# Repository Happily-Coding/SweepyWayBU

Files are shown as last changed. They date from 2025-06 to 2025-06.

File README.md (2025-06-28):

# SweepyWay Split Keyboard
A truly ergonomic, begginner friendly keyboard.

## Photos & Outputs

left side | right side
-|-
left | right

[More outputs](https://happily-coding.github.io/SweepyWay/) 
<!-- 
![left bottom](https://happily-coding.github.io/SweepyWay/images/left_pcb-bottom.png) | ![right bottom](https://happily-coding.github.io/SweepyWay/images/right_pcb-bottom.png)
-->

## Features
* **Beginner friendly**
  * Abundant keys, but in non disruptive places.
* **Truly ergonomic**
  * Aggressive column stagger, like Ferris Sweep, to match how fingers are staggered.
  * Choc V1 keys
    * Very low actuation force switches available (example: nocturnal)
    * Low profile (seamless use without handrest, easier to adjust height without an adjustable desk)
    * ChocV1 spacing (reach the outer columns with less over-stretching)
  * Tenting, negative tilting, adjustable height and hand rest solutions
* **Energy efficient**
  * [Nice!nano](https://nicekeyboards.com/nice-nano) optimised, but any promicro should work (bottom up) 
  * [Nice!view](https://nicekeyboards.com/nice-view) support
  * No leds
* **Accident prepared** 
  * Controller far away from accidental splash zones,
  * Power switch for transport
  * No metal plates to help prevent static discharge from friying the keyboard
  * Hotswappable battery, switches, keycaps, controller, and case. Replace anything that breaks or you dislike.
    * You can even remove the components and use them with a different pcb.
* **Easy to modify** (Declarative design done via yaml)
  * Layout is declared using [Ergogen](https://github.com/mrzealot/ergogen/). 
  * Uses Ergogen to translate YAML to a KiCad PCB and plate files for FR-4 fab or laser cutting
  * Uses [kicad-automation-scripts](https://github.com/productize/kicad-automation-scripts) and [FreeRouting](https://github.com/freerouting/freerouting) to **automatically route the traces on the PCB**
  * Uses [KiKit](https://github.com/yaqwsx/KiKit) to render PCB previews and production-ready **Gerber files**

## Build Status


<!-- from original repo
## Todo
Mio:
Paso 1: mover todos los electronicos para arriba con mismo ofset
mcu_nice_nano
display_nice_view
battery_connector_jst_ph_2
reset_switch_tht_top
utility_ergogen_logo
version_txt
power_switch_smd_side
polygon arriba

Paso 2: sacar cosas raras/ tratar de simplificar el file

Paso 3:
hay que recrear el area, y reorganizar componentes como mi original
hay que recrear el outline y organizar componentes como el original (pero todavia no)

* Bottom Plate (Thick PCB with cutouts for all components placed at the bottom. Optimised for maximum thinness)
* Remove or document magic numbers
* SMD footrints
* Middle bracked PCB with touchpad (Holds both halves together rigidly)
* stabilizer cutouts Needs more research...
  Thanks https://github.com/jasonhazel for measuring the ChocFox WOB 3u spacebar stabilizer spacing. (40mm)
  watch https://www.youtube.com/watch?v=5tERUZ_BSPM
-->

## How to modify it
<!-- from original repo
### Add more keys in places that don't interfere with the controller
Add elements to the row or column matrix, and map them (WIP, TODO explain with more detail)

### Use other controllers

### Use mx switches / chocv2 switches

### Use other battery/reset switches/ footprints
See this examples: 
https://github.com/jsbursik/Janus-Keyboard mx nice nano reversible with custom footprints
https://github.com/tarneaux/triboard xiao controller choc spaced reversible with battery polygon!
https://github.com/Henkru/novum mx with jlpcb target, middle layer for stability, and awesome background art
https://github.com/Musab-Hassan/aurora_keyboard very detailed, and well organized mx example
https://github.com/soundmonster/samoklava/tree/main
https://github.com/christianselig/caldera-keyboard/blob/main/ergogen/config.yaml
https://github.com/jusdisgi/splaveferris/blob/main/ergogen/config.yaml (choc v1, smd) <-- reference for mirrored
https://github.com/jusdisgi/biggie-splays/blob/main/biggie-splays_choc_v1/config.yaml mirror matrix
https://pastebin.com/JzsmATYZ celoide reversible (obtianed from atreus/absolem discord) https://cdn.discordapp.com/attachments/759825860617437204/1376609916986327150/pleiades.yaml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
Complex case, and mounting example with celodie footpritns https://github.com/MalusKnight/SplitMax-Ergogen/blob/main/config.yaml and oleds
https://github.com/Nuclear-Squid/Quacken/blob/main/config.yaml [ro micro non celoide]
https://peterlyons.com/problog/2024/05/kipra-keyboard/ how to load an ergogen otuput to freecad 
https://github.com/johnlamb/LambBT/blob/main/ergogen/config.yaml case, m2 screwes, etc 
https://github.com/AtomicJon/jonkey/blob/main/jonkey-v2.yml other celoide footprints usage
https://github.com/scipioni/clavis alternative stup for auto routing 
#asym in theory can be used in outlines to get only mirrored or only normal points https://docs.ergogen.xyz/outlines/
-->

If you would like to modify this:
* fork it
* change `ergogen/config.yaml` to your liking
* reactivate github workflows
* reactivate github pages at https://github.com/your-name/your-repo/settings/pages, choose github actions instead of a branch
* push your changes; the `build.yml` GitHub Workflow will pick it up, autoroute and generate Gerbers, all in a zip file.
  See https://github.com/soundmonster/samoklava/actions
* or:
  * make sure to have Docker CLI and NodeJS installed
  * run `make setup clean all`
  * check the `output` folder for KiCad PCBs and Gerbers
* you can find the latest build artifacts [here](https://happily-coding.github.io/SweepyWay/)

See the [workflow](.github/workflows/build.yml) or the [Makefile](Makefile) for more details.

## Credits
- [mxooaar](https://www.reddit.com/r/ErgoMechKeyboards/comments/1lanvon/comment/mxooaar/) for peaking my interest in actually building my idea for a keyboard
- [christianselig caldera keyboard](https://github.com/christianselig/caldera-keyboard) for showing that creating a custom keyboard was reasonably easy
- [Ergogen](https://github.com/ergogen/ergogen) for the awesome tool for building most of the keyboard
- [Soundmonster Samaklova Keyboard](https://github.com/soundmonster/samoklava/tree/main) for automatic electronic routing
- [tbaumann typematrix](https://github.com/tbaumann/typematrix_split_new/tree/main/ergogen) for automatic documentation, and example of how to use celoide ergonomic footprints
- [Celoide](https://github.com/ceoloide/ergogen-footprints) for the library of additional ergogen footprints for more parts.

## Disclaimer
**Work in progress!**

## Important
Only connect battery if a nice!nano board is used!

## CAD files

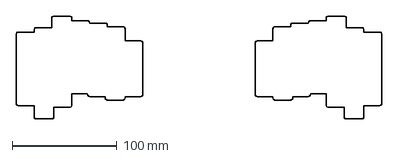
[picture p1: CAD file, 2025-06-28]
ergogen/output/outlines/key_based_board_outline_left.dxf
349.0 x 98.2 mm

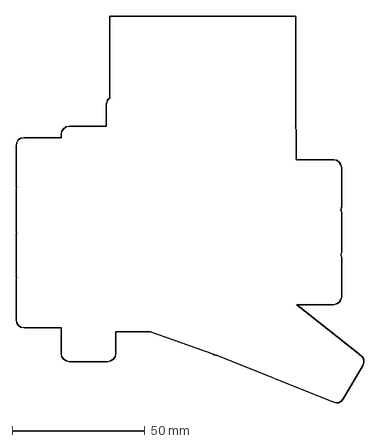
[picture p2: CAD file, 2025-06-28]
ergogen/output/outlines/l_pcb_outline.dxf
131.3 x 146.0 mm

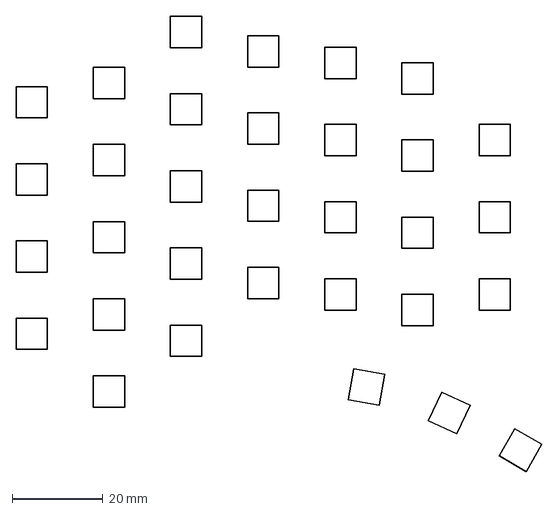
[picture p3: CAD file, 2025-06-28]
ergogen/output/outlines/l_keys_outline.dxf
115.9 x 100.3 mm

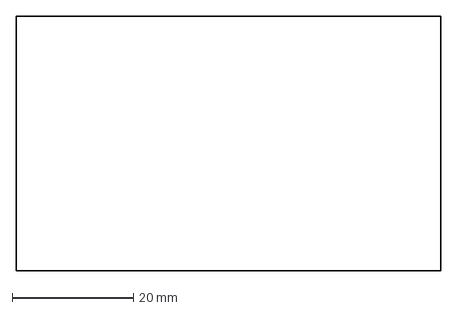
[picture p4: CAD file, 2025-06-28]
ergogen/output/outlines/l_controller_area.dxf
70.0 x 42.0 mm

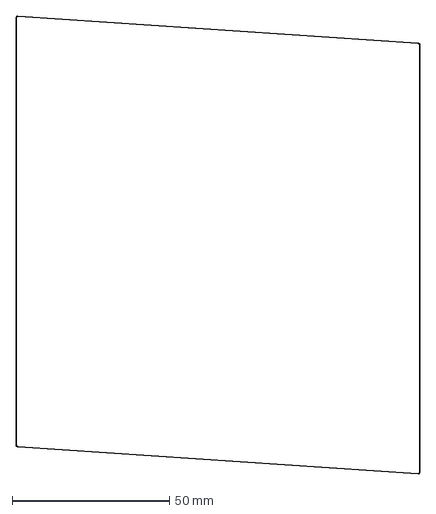
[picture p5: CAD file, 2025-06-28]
ergogen/output/outlines/bottomright.dxf
128.5 x 145.6 mm

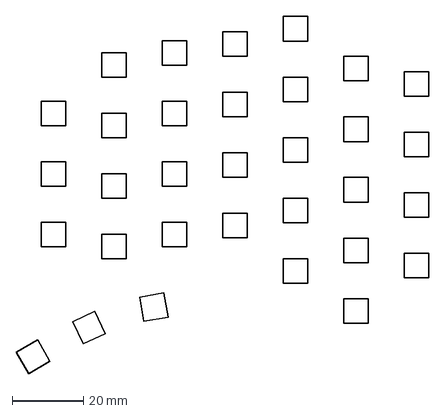
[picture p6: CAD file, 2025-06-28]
ergogen/output/outlines/r_keys_outline.dxf
115.9 x 100.3 mm

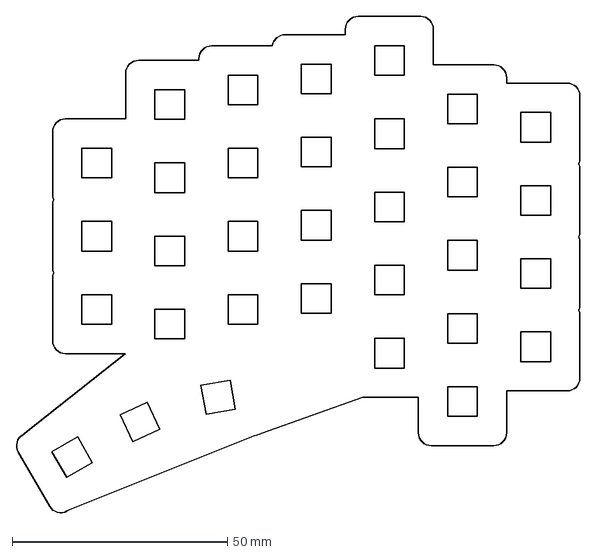
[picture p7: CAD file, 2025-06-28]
ergogen/output/outlines/r_cover_outline.dxf
131.0 x 115.7 mm

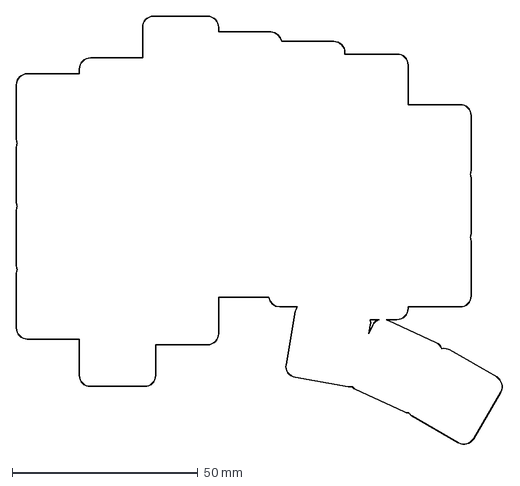
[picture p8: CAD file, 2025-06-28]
ergogen/output/outlines/l_key_based_board_outline.dxf
131.3 x 115.7 mm

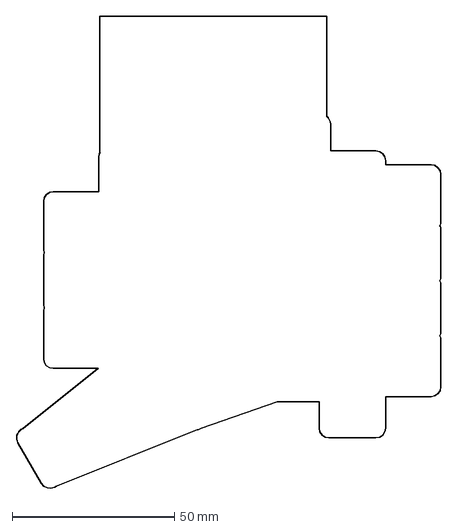
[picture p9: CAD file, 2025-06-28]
ergogen/output/outlines/r_pcb_outline.dxf
131.0 x 146.0 mm

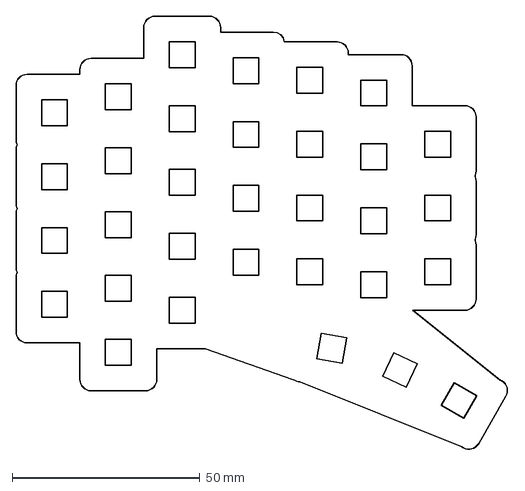
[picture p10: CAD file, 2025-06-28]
ergogen/output/outlines/l_cover_outline.dxf
131.3 x 115.7 mm

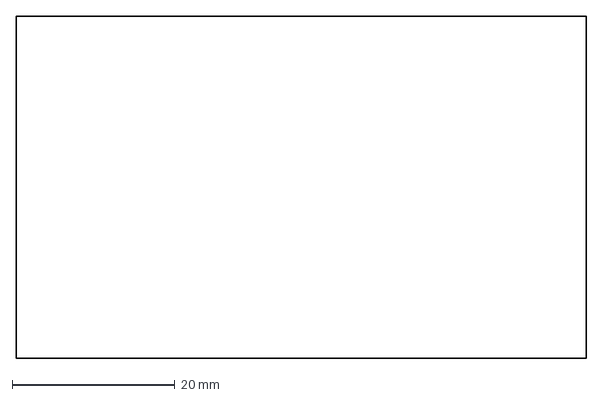
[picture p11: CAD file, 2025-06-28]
ergogen/output/outlines/r_controller_area.dxf
70.0 x 42.0 mm

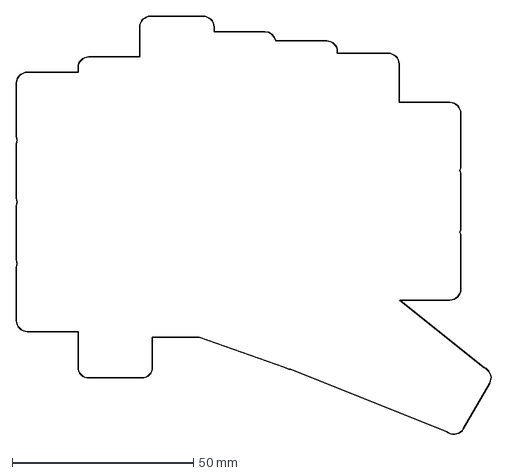
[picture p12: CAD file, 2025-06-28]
ergogen/output/outlines/l_all_key_clusters_outline.dxf
131.3 x 115.7 mm

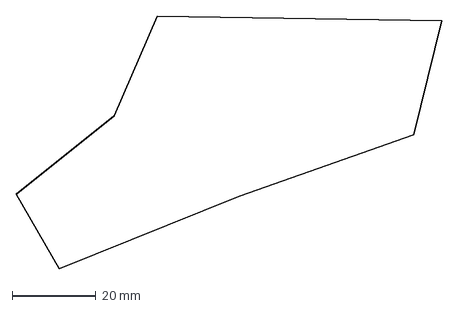
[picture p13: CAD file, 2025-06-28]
ergogen/output/outlines/r_thumb_suplementary_outline.dxf
101.7 x 60.2 mm

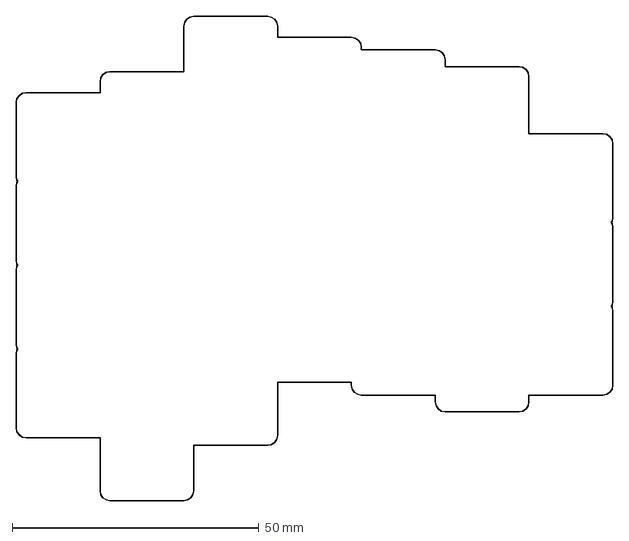
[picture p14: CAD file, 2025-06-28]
ergogen/output/outlines/key_based_board_outline.dxf
121.0 x 98.2 mm

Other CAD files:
ergogen/output/outlines/all_key_clusters_outline.dxf
ergogen/output/outlines/topleft.dxf
ergogen/output/outlines/thumb_suplementary_outline.dxf
ergogen/output/outlines/bottomleft.dxf
ergogen/output/outlines/combined.dxf
ergogen/output/outlines/cover_outline.dxf
ergogen/output/outlines/l_thumb_suplementary_outline.dxf
ergogen/output/outlines/left_pcb_outline.dxf
ergogen/output/outlines/pcb_left.dxf
ergogen/output/outlines/r_all_key_clusters_outline.dxf
ergogen/output/outlines/r_key_based_board_outline.dxf
ergogen/output/outlines/topright.dxf

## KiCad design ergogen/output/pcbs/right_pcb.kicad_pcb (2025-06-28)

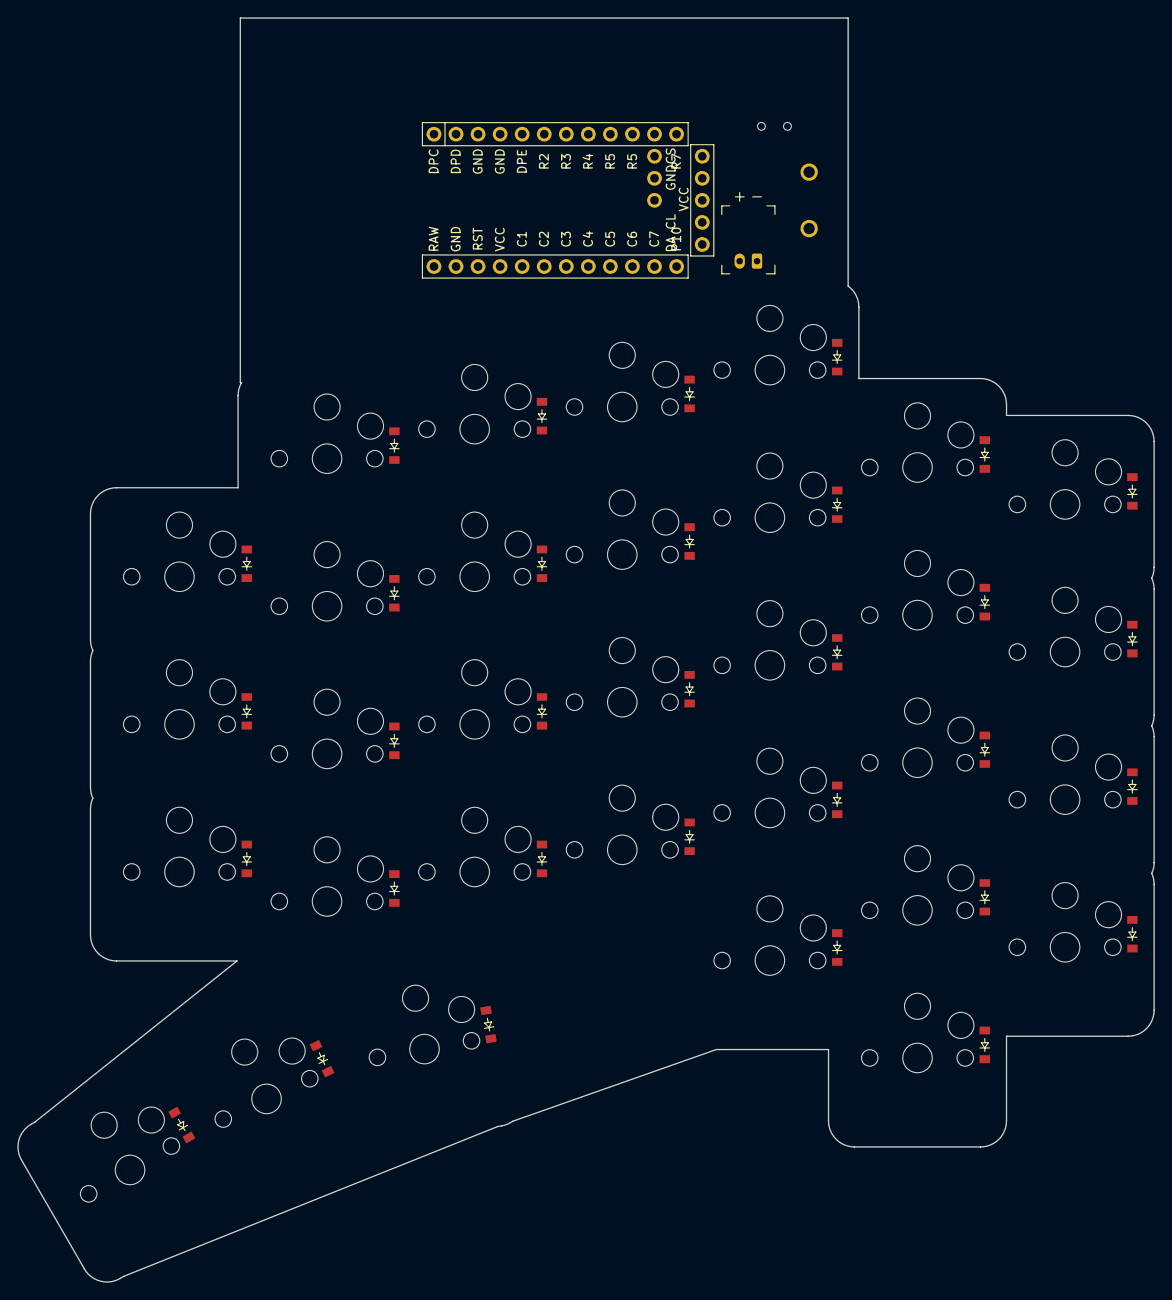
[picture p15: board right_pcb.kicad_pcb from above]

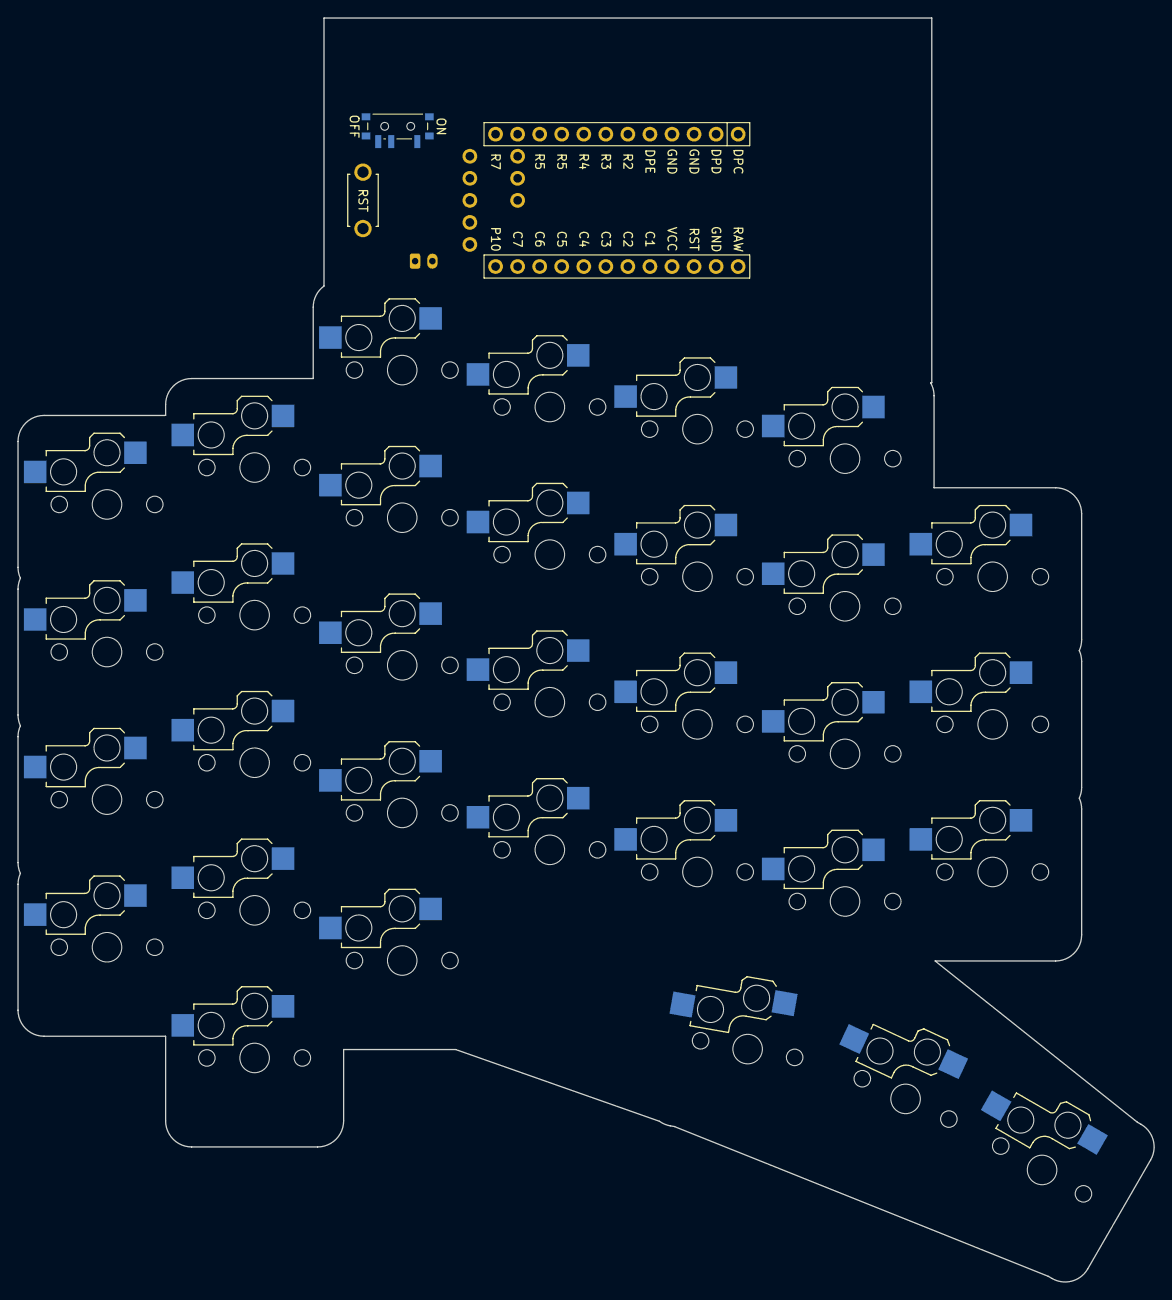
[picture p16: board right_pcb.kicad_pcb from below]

Board: 2 copper layers, 130.8 x 145.6 mm, 69 parts (34 on the bottom side), 52 nets, no tracks yet.

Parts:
D1, D2, D3, D4, D5, D6, D7, D8, D9, D10, D11, D12, D13, D14, D15, D16, D17, D18, D19, D20, D21, D22, D23, D24, D25, D26, D27, D28, D29, D30, D31, D32: diode_tht_sod123
DISP1: display_nice_view
JST1: battery_connector_jst_ph_2
MCU1: mcu_nice_nano
PWR1: power_switch_smd_side
RST1: reset_switch_tht_top
S1, S2, S3, S4, S5, S6, S7, S8, S9, S10, S11, S12, S13, S14, S15, S16, S17, S18, S19, S20, S21, S22, S23, S24, S25, S26, S27, S28, S29, S30, S31, S32: switch_choc_v1_v2

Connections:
BAT_P: JST1.2, PWR1.1
C1: MCU1.20, S1.2, S2.2, S3.2, S4.2
C2: MCU1.19, S5.2, S6.2, S7.2, S8.2, S9.2
C3: MCU1.18, S10.2, S11.2, S12.2, S13.2, S14.2
C4: MCU1.17, S15.2, S16.2, S17.2, S18.2
C5: MCU1.16, S19.2, S20.2, S21.2, S22.2
C6: MCU1.15, S23.2, S24.2, S25.2, S26.2
C7: MCU1.14, S27.2, S28.2, S29.2
DPC: DISP1.4, MCU1.1
DPD: DISP1.5, MCU1.2
DPE: DISP1.1, MCU1.5
GND: DISP1.2, JST1.1, MCU1.3, MCU1.4, MCU1.23, RST1.2
R1: D4.1, D9.1, D14.1, D18.1, D22.1, D26.1
R2: D3.1, D8.1, D13.1, D17.1, D21.1, D25.1, D29.1, MCU1.6
R3: D2.1, D7.1, D12.1, D16.1, D20.1, D24.1, D28.1, MCU1.7
R4: D1.1, D6.1, D11.1, D15.1, D19.1, D23.1, D27.1, MCU1.8
R5: D5.1, D10.1, D30.1, D31.1, D32.1, MCU1.9, MCU1.10
RAW: MCU1.24, PWR1.2
RST: MCU1.22, RST1.1
VCC: DISP1.3, MCU1.21
mirror_col1_row1: D4.2, S4.1
mirror_col1_row2: D3.2, S3.1
mirror_col1_row3: D2.2, S2.1
mirror_col1_row4: D1.2, S1.1
mirror_col1_thumb_row_1: D30.2, S30.1
mirror_col2_row1: D9.2, S9.1
mirror_col2_row2: D8.2, S8.1
mirror_col2_row3: D7.2, S7.1
mirror_col2_row4: D6.2, S6.1
mirror_col2_row5: D5.2, S5.1
mirror_col2_thumb_row_1: D31.2, S31.1
mirror_col3_row1: D14.2, S14.1
mirror_col3_row2: D13.2, S13.1
mirror_col3_row3: D12.2, S12.1
mirror_col3_row4: D11.2, S11.1
mirror_col3_row5: D10.2, S10.1
mirror_col3_thumb_row_1: D32.2, S32.1
mirror_col4_row1: D18.2, S18.1
mirror_col4_row2: D17.2, S17.1
mirror_col4_row3: D16.2, S16.1
mirror_col4_row4: D15.2, S15.1
mirror_col5_row1: D22.2, S22.1
mirror_col5_row2: D21.2, S21.1
mirror_col5_row3: D20.2, S20.1
mirror_col5_row4: D19.2, S19.1
mirror_col6_row1: D26.2, S26.1
mirror_col6_row2: D25.2, S25.1
mirror_col6_row3: D24.2, S24.1
mirror_col6_row4: D23.2, S23.1
mirror_col7_row2: D29.2, S29.1
mirror_col7_row3: D28.2, S28.1
mirror_col7_row4: D27.2, S27.1

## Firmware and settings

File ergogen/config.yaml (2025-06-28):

meta:
  engine: 4.1.0
  name: SweepyWay
  version: &kb_version v0.2
  author: Happily-Coding
  url: &kb_url https://github.com/Happily-Coding/SweepyWay/

  # These presets provide different layout options
  # Select a preset in the `units` section below
presets:
  choc:
    # Standard Choc spacing
    kx: 17 # spacing between key ccol7s (X-axis)
    ky: 18 # spacing between key ccol7s (Y-axis)
    px: 3.5 #How much to pad horizontally
    py: 3.5 #how much to pad vertically
    plate_kx: 13.8 # key cutout hole width (cherry, choc v2: 14, choc v1: 13.8)
    plate_ky: 13.8 # key cutout hole height (cherry, choc v2: 14, choc v1: 13.8)
    keycap_x_1u: 17.5
    keycap_y_1u: 16.5
    keycap_x_1_5u: cx * 1.5 - 0.5 
    keycap_x_1_5u_span: cx*1.25
    vertical_diode_shift: 1.5 # How much to shift to avoid overlap
    horizontal_diode_shift: -0.5 plate_kx - 0.85
    diode_rotation: -180 # Diode rotation
    switch_rotation: 180 # Hotswap south, led north
  cfx:
    # CFX 1u are 15.5x15x5 keys for a tighter 17x17 matrix.  This is an idealised grid as to my knowledge no 1.5u keycaps exist for that size
    $extends: presets.choc
    kx: 17 # spacing between key ccol7s (X-axis)
    ky: 17 # spacing between key ccol7s (Y-axis)
    keycap_x_1u: 16.5
  chocfox_wob:
    # ChocFox WOB 1u are CFX. However the larger keys don't work on that grid.
    $extends: presets.cfx
    keycap_x_1_5u: 26
    keycap_x_1_5u_span: 13.25 + kx/2


units:
  $extends: presets.chocfox_wob

  # Physical measures
  screw_radius: 1.1 # M2 screws
  screw_diameter: screw_radius * 2
  screw_head_radius: 2.05
  screw_head_diameter: screw_head_radius * 2
  spacer_radius: 2.15 # M2 standoffs
  spacer_diameter: spacer_radius * 2
  fillet_radius: 0.5
  via_size: 0.56 # JLCPCB min 0.56 | KiCad default 0.8
  via_drill: 0.3 # JLCPCB min 0.3 | KiCad default 0.4

  # Case variables
  case_wall_thickness: 1.2
  pcb_to_case_wall_tolerance: 0.25
  bottom_plate_thickness: 1.0
  top_plate_thickness: 1.6
  internal_distance_between_plates: 4

  # Font units
  font_x: 1
  font_y: 1
  font_xo: 0.5 font_x
  font_yo: 0.5 * font_y

  # Nice Nano
  mcu_spacing_x: 2.72
  mcu_x: 17.78 + mcu_spacing_x
  mcu_y: 33.02
  mcu_xo: 0.5 * mcu_x
  mcu_yo: 0.5 * mcu_y  

  # Nice!View display
  disp_x: 14
  disp_y: 36
  disp_jumper_y: 2.6
  disp_xo: 0.5 * disp_x
  disp_yo: 0.5 * disp_y

  # Battery Connector
  batc_x: 4.3
  batc_y: 4.6
  batc_xo: 0.5 * batc_x
  batc_yo: 0.5 * batc_y

  # Battery Pads
  batp_x: 3.75
  batp_y: 2.5
  batp_xo: 0.5 * batp_x
  batp_yo: 0.5 * batp_y

  # Power Switch
  sw_power_x: 3.1
  sw_power_y: 8.3
  sw_power_xo: 0.5 * sw_power_x
  sw_power_yo: 0.5 * sw_power_y

  # Reset Switch
  sw_reset_x: 3.4
  sw_reset_y: 5
  sw_reset_xo: 0.5 * sw_reset_x
  sw_reset_yo: 0.5 * sw_reset_y

  #ncu bumps
  controller_bump_x: 3kx
  controller_bump_y: mcu_x 
  controller_bump_shift: kx
  
  controller_area_y_pad: 11

points:
  key:
    padding: ky
    spread: kx
    width: keycap_x_1u
    height: keycap_x_1u
    mirror: #When they are mirrored tag them with test
      tags: ["key", "rightkey"]
  zones:
    matrix:
      # Fix placement on KiCAD sheet.
      anchor:
        shift: [35, -150]
      key.tags: [
        "key",
        "leftkey"
        ] #When keys are not mirrored tag them with key, right
      columns:
        col1:
          key.column_net: C1
          key.stagger: 0
          rows:
            row5:
              skip: true
        col2:
          key.column_net: C2
          key.stagger: 0.25 ky
        col3:
          key.column_net: C3
          key.stagger: 0.66 ky
        col4:
          key.column_net: C4
          key.stagger: -0.25 ky
          rows:
            row5:
              skip: true
        col5:
          key.column_net: C5
          key.stagger: -0.15 ky
          rows:
            row5:
              skip: true
        col6:
          key.column_net: C6
          key.stagger: -0.2 ky
          rows:
            row5:
              skip: true
        col7:
          key.column_net: C7
          key.stagger: .2 ky
          rows:
            row1:
              skip: true
            row5:
              skip: true
      rows:
        row5:
          row_net: R5
        row4:
          row_net: R4
        row3:
          row_net: R3
        row2:
          row_net: R2
        row1:
          row_net: R1
      mirror:
        #shift: [35, -150]
        distance: 340
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
